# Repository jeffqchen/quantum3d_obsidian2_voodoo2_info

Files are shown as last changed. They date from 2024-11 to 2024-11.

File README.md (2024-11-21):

# Quantum3D Obsidian2 Arcade Voodoo2 Info

q3d_cover

I have luckily obtained TWO Quantum3D Obsidian2 arcade Voodoo2 cards from a kind eBay seller. They were both broken, so I spend a few weeks investigating and fixing them up, plus designing upgrades to enhance its functionalities. I hope my work will help some of you repair and make your Q3D cards work better.

## Add-on Projects

I have designed the following mods for this card.
- VGA Input Board
- U21 Xilinx CPLD Replacement
- SLI Bridge. Both rigid & ribbon type
- Protective Armor

### VGA Input Board

 

The Q3D arcade card does not come with a VGA input like a retail Voodoo 2 card. However, it has a pin header footprint on the PCB for that purpose.

I have designed a PCB to plug into the pin header, so you can add a VGA male port, plug in the VGA output of your 2D video card via that Voodoo passthrough cable.

### U21 Xilinx CPLD Replacement

 

The U21 chip, a Xilinx CPLD, controls mainly sync signals that's output to the VGA output.

There seems to be a few situations wit this chip.
- Some arcade boards come with a security setup and this chip won't function as-is.
- Sometimes this Xilinx chip dies, and you won't have any video output on the screen.

Both situations will render the card useless. I designed a simple logic circuit to function similarly to the unlocked Xilinx CPLD.

### SLI Bridge

 

This card can do SLI! However you need to add in a few missing components before that. With that part taken care of, I've come up with a rigid SLI bridge board that helps you SLI two of these same cards, or with a reference card. The info on how to create a ribbon type cable will also be available.

### Protective Armor

This set of 3D printed armor will protect sensitive SMD components and improve handling of the card, while making the card look way more nicer. It wouldn't hurt to try!



 

## Mods

 

Solder on 2MB of EDO RAM chips to the FBI on the back of the card to make it a 12MB Voodoo 2.

 

Restore picture brightness to the full PC standard.

All information is available in the [Project Wiki](https://github.com/jeffqchen/quantum3d_obsidian2_voodoo2_info/wiki) pages.

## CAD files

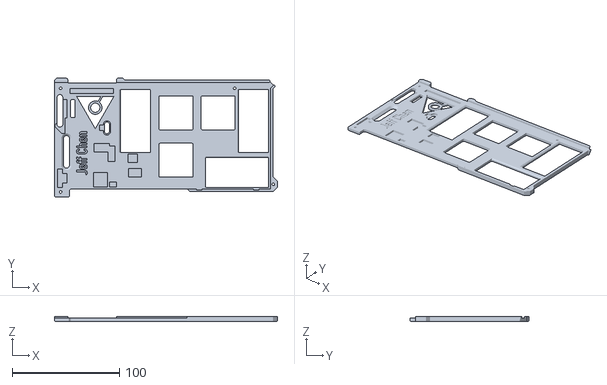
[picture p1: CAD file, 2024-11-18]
3D Print/Armor/Back.stl
208.2 x 111.2 x 5.00

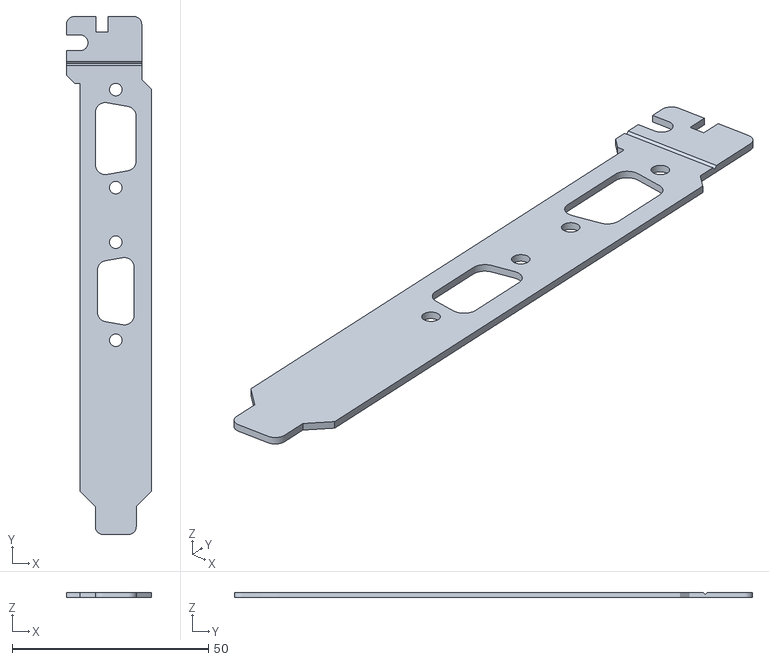
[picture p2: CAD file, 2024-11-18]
3D Print/Q3D VGA Bracket.stl
21.7 x 132.0 x 1.30

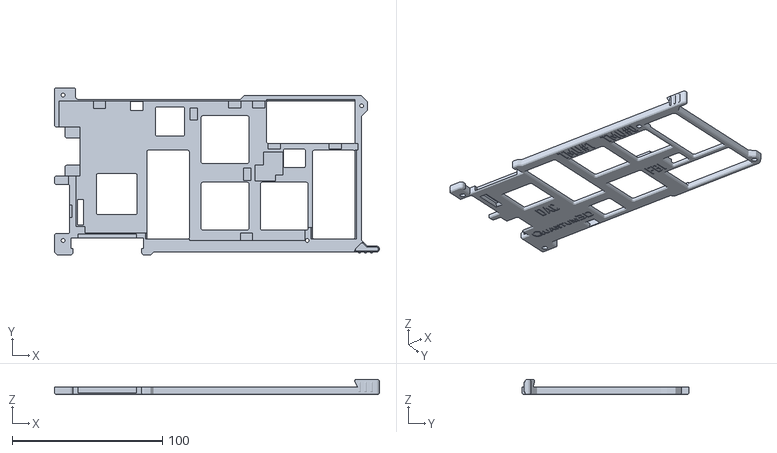
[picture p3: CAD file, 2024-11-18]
3D Print/Armor/Front.stl
216.2 x 111.2 x 10.0

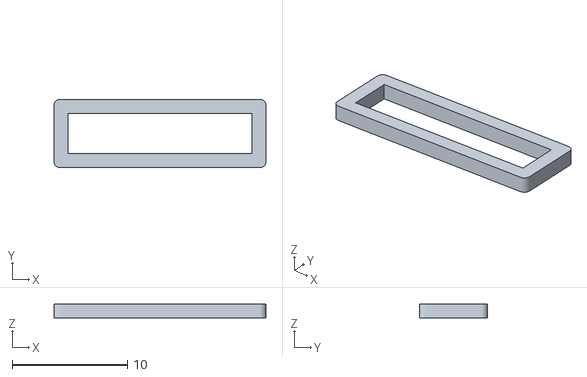
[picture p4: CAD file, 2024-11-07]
3D Print/VGA Pin Header Spacer.stl
18.4 x 5.90 x 1.25

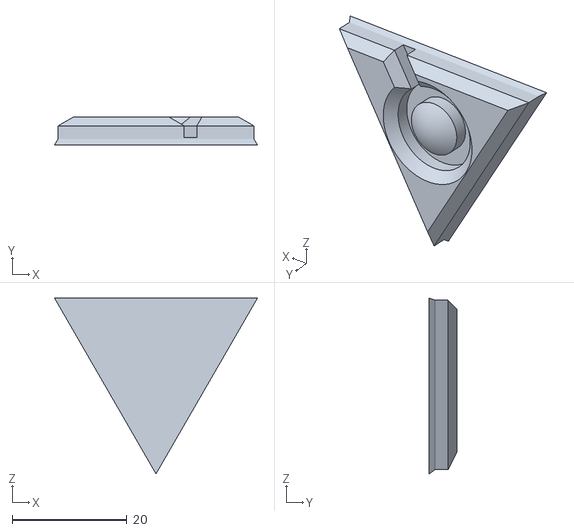
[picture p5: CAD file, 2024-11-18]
3D Print/Armor/Quantum3D Logo 3D.stl
35.4 x 4.80 x 30.6

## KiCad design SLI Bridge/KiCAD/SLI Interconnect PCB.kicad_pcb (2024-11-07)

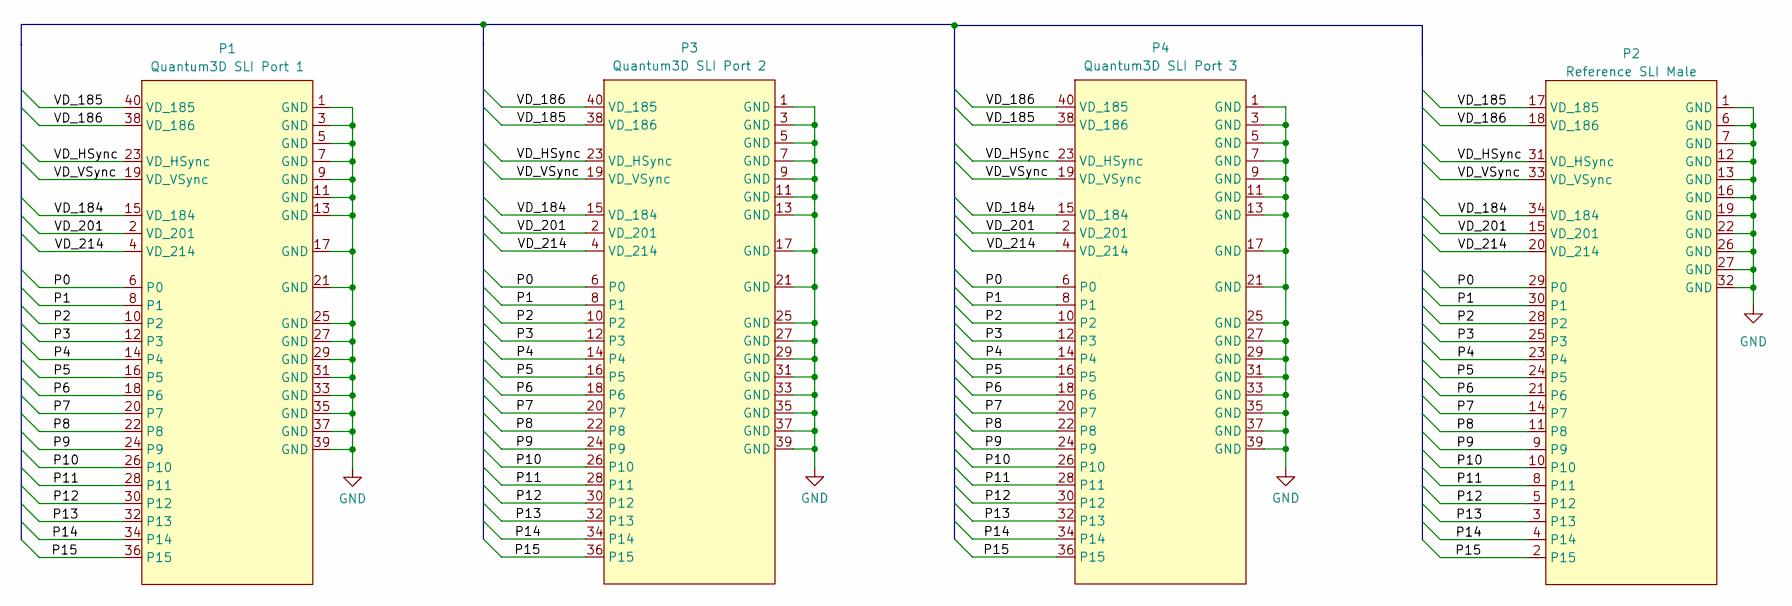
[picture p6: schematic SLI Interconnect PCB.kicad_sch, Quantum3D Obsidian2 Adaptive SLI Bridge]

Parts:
P1: Quantum3D SLI Port 1; Quantum3D_SLI_JP2_Female
P2: Reference SLI Male; Reference_SLI_Male
P3: Quantum3D SLI Port 2; Quantum3D_SLI_JP2_Female
P4: Quantum3D SLI Port 3; Quantum3D_SLI_JP2_Female

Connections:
/P0: P1.6 (P0), P2.29 (P0), P3.6 (P0), P4.6 (P0)
/P1: P1.8 (P1), P2.30 (P1), P3.8 (P1), P4.8 (P1)
/P2: P1.10 (P2), P2.28 (P2), P3.10 (P2), P4.10 (P2)
/P3: P1.12 (P3), P2.25 (P3), P3.12 (P3), P4.12 (P3)
/P4: P1.14 (P4), P2.23 (P4), P3.14 (P4), P4.14 (P4)
/P5: P1.16 (P5), P2.24 (P5), P3.16 (P5), P4.16 (P5)
/P6: P1.18 (P6), P2.21 (P6), P3.18 (P6), P4.18 (P6)
/P7: P1.20 (P7), P2.14 (P7), P3.20 (P7), P4.20 (P7)
/P8: P1.22 (P8), P2.11 (P8), P3.22 (P8), P4.22 (P8)
/P9: P1.24 (P9), P2.9, P3.24 (P9), P4.24 (P9)
/P10: P1.26 (P10), P2.10, P3.26 (P10), P4.26 (P10)
/P11: P1.28 (P11), P2.8 (P11), P3.28 (P11), P4.28 (P11)
/P12: P1.30 (P12), P2.5 (P12), P3.30 (P12), P4.30 (P12)
/P13: P1.32 (P13), P2.3 (P13), P3.32 (P13), P4.32 (P13)
/P14: P1.34 (P14), P2.4 (P14), P3.34 (P14), P4.34 (P14)
/P15: P1.36 (P15), P2.2 (P15), P3.36 (P15), P4.36 (P15)
/VD_184: P1.15 (VD_184), P2.34 (VD_184), P3.15 (VD_184), P4.15 (VD_184)
/VD_185: P1.40 (VD_185), P2.17 (VD_185), P3.38 (VD_186), P4.38 (VD_186)
/VD_186: P1.38 (VD_186), P2.18 (VD_186), P3.40 (VD_185), P4.40 (VD_185)
/VD_201: P1.2 (VD_201), P2.15 (VD_201), P3.2 (VD_201), P4.2 (VD_201)
/VD_214: P1.4 (VD_214), P2.20 (VD_214), P3.4 (VD_214), P4.4 (VD_214)
/VD_HSync: P1.23 (VD_HSync), P2.31 (VD_HSync), P3.23 (VD_HSync), P4.23 (VD_HSync)
/VD_VSync: P1.19 (VD_VSync), P2.33 (VD_VSync), P3.19 (VD_VSync), P4.19 (VD_VSync)
GND: P1.1 (GND), P1.3 (GND), P1.5 (GND), P1.7 (GND), P1.9 (GND), P1.11 (GND), P1.13 (GND), P1.17 (GND), P1.21 (GND), P1.25 (GND), P1.27 (GND), P1.29 (GND), P1.31 (GND), P1.33 (GND), P1.35 (GND), P1.37 (GND), P1.39 (GND), P2.1 (GND), P2.6 (GND), P2.7 (GND), P2.12 (GND), P2.13 (GND), P2.16 (GND), P2.19 (GND), P2.22 (GND), P2.26 (GND), P2.27 (GND), P2.32 (GND), P3.1 (GND), P3.3 (GND), P3.5 (GND), P3.7 (GND), P3.9 (GND), P3.11 (GND), P3.13 (GND), P3.17 (GND), P3.21 (GND), P3.25 (GND), P3.27 (GND), P3.29 (GND), P3.31 (GND), P3.33 (GND), P3.35 (GND), P3.37 (GND), P3.39 (GND), P4.1 (GND), P4.3 (GND), P4.5 (GND), P4.7 (GND), P4.9 (GND), P4.11 (GND), P4.13 (GND), P4.17 (GND), P4.21 (GND), P4.25 (GND), P4.27 (GND), P4.29 (GND), P4.31 (GND), P4.33 (GND), P4.35 (GND), P4.37 (GND), P4.39 (GND)

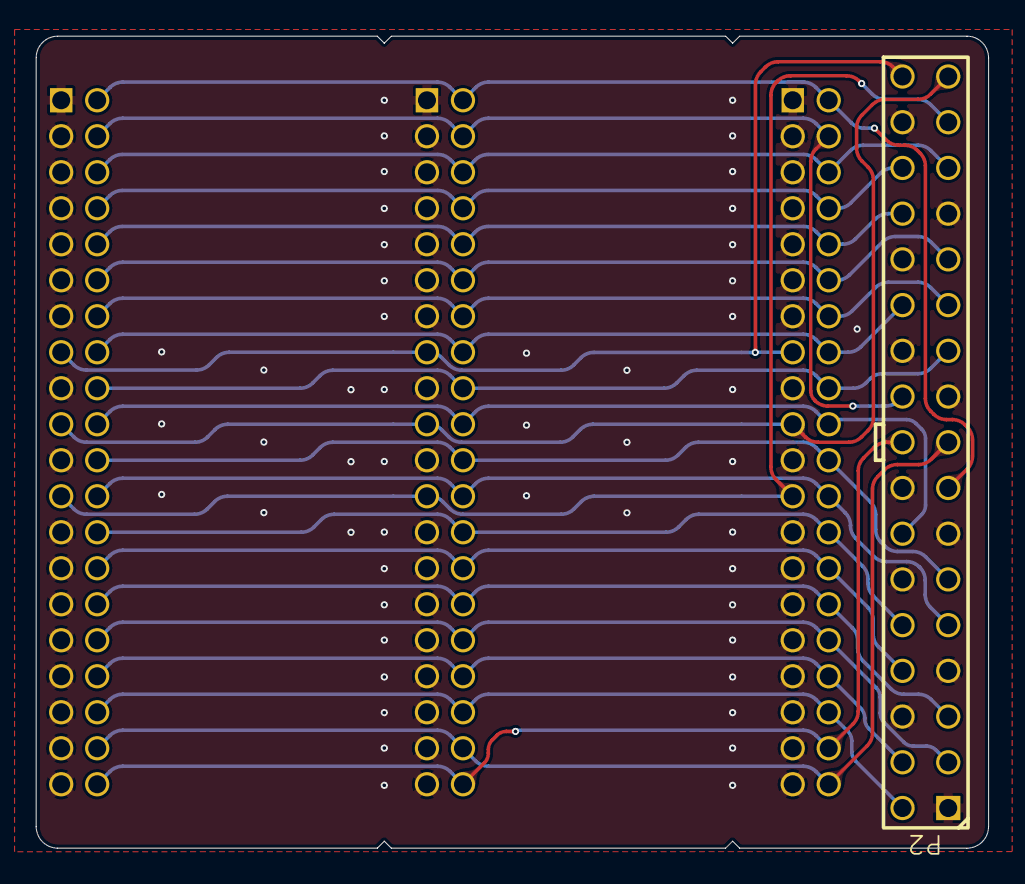
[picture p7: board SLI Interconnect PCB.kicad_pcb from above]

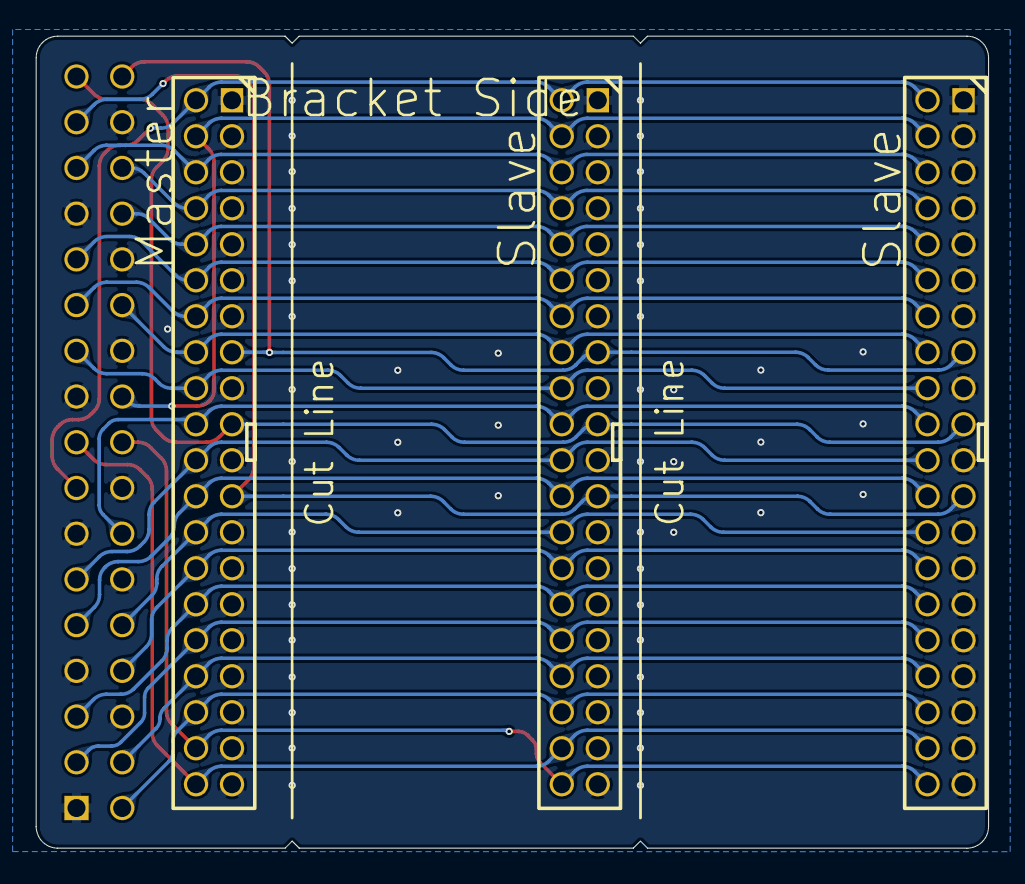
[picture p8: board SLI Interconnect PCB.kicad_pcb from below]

Board: 2 copper layers, 52.9 x 45.1 mm, 4 parts (3 on the bottom side), 24 nets.

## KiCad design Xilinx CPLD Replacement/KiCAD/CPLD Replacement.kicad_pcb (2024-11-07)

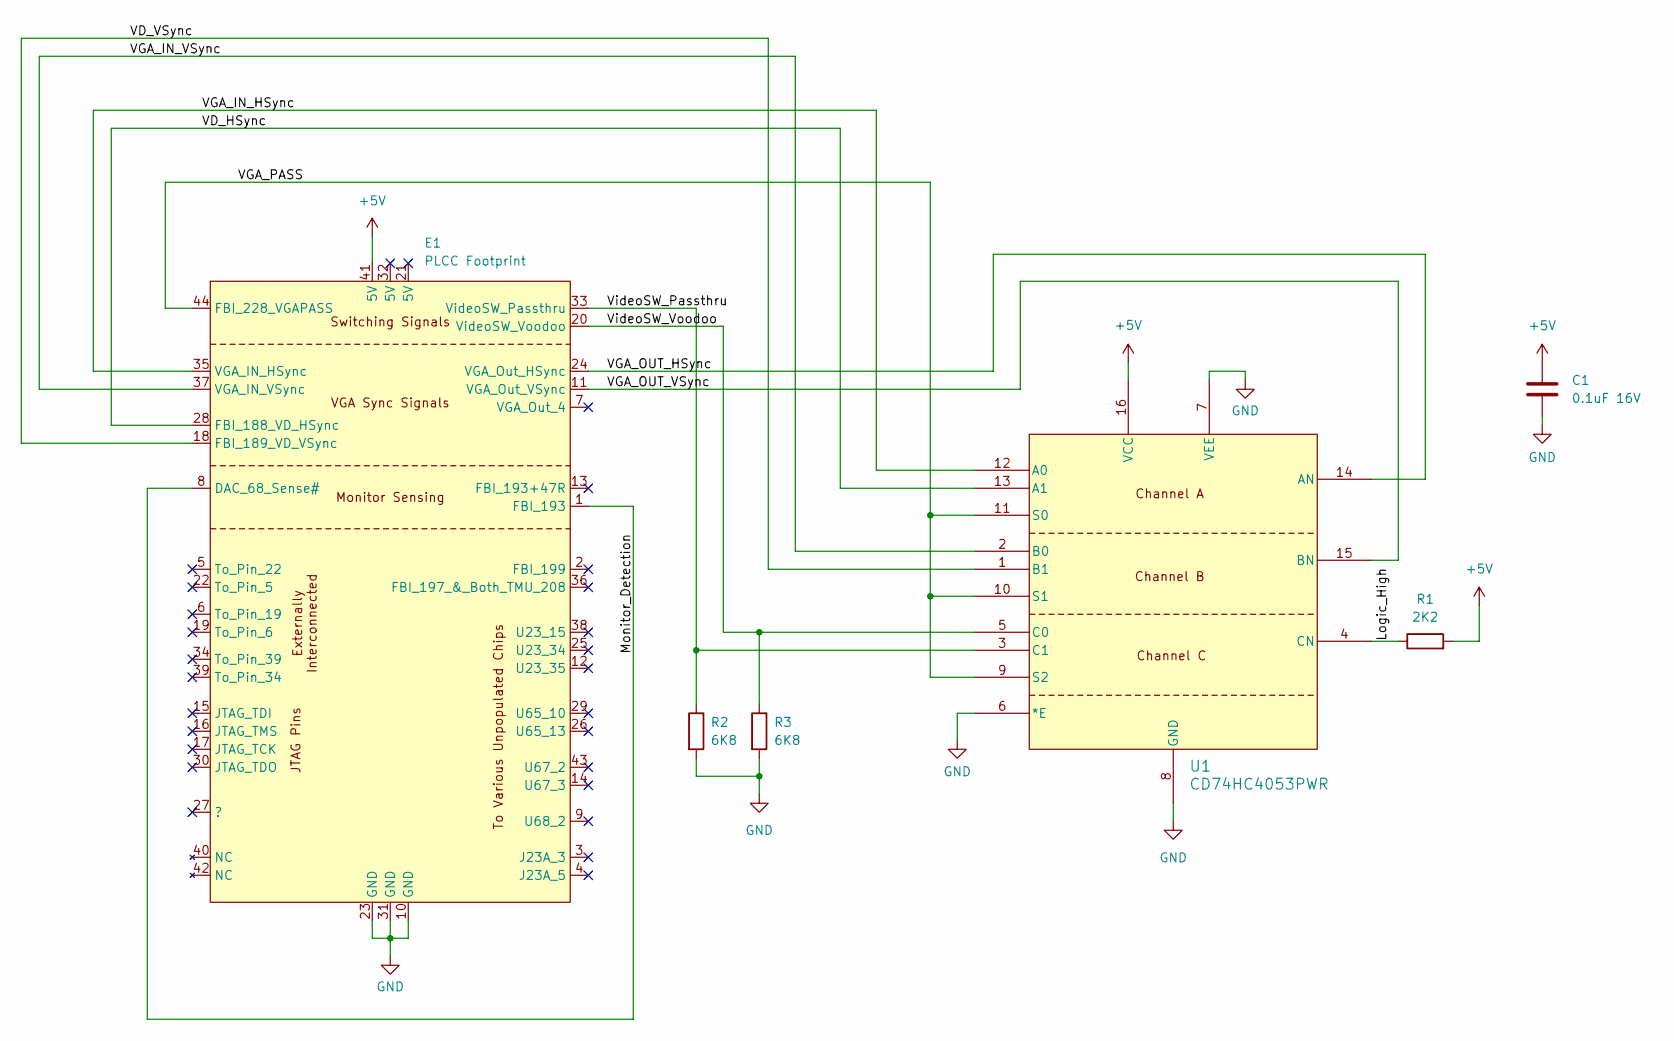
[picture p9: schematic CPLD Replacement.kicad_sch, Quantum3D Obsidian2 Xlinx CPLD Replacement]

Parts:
C1: 0.1uF 16V; R_0603_1608Metric_Pad0.98x0.95mm_HandSolder
E1: PLCC Footprint; CPLD_Replacement_44
R1: 2K2; R_0603_1608Metric_Pad0.98x0.95mm_HandSolder
R2, R3: 6K8; R_0603_1608Metric_Pad0.98x0.95mm_HandSolder
U1: CD74HC4053PWR; PW16

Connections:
+5V: C1.1, E1.41 (5V), R1.2, U1.16 (VCC)
/Logic_High: R1.1, U1.4 (CN)
/Monitor_Detection: E1.1 (FBI_193), E1.8 (DAC_68_Sense#)
/VD_HSync: E1.28 (FBI_188_VD_HSync), U1.13 (A1)
/VD_VSync: E1.18 (FBI_189_VD_VSync), U1.1 (B1)
/VGA_IN_HSync: E1.35 (VGA_IN_HSync), U1.12 (A0)
/VGA_IN_VSync: E1.37 (VGA_IN_VSync), U1.2 (B0)
/VGA_OUT_HSync: E1.24 (VGA_Out_HSync), U1.14 (AN)
/VGA_OUT_VSync: E1.11 (VGA_Out_VSync), U1.15 (BN)
/VGA_PASS: E1.44 (FBI_228_VGAPASS), U1.9 (S2), U1.10 (S1), U1.11 (S0)
/VideoSW_Passthru: E1.33 (VideoSW_Passthru), R2.1, U1.3 (C1)
/VideoSW_Voodoo: E1.20 (VideoSW_Voodoo), R3.1, U1.5 (C0)
GND: C1.2, E1.10 (GND), E1.23 (GND), E1.31 (GND), R2.2, R3.2, U1.6 (*E), U1.7 (VEE), U1.8 (GND)

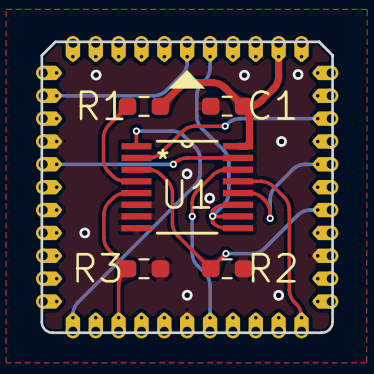
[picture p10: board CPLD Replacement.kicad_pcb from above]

Board: 2 copper layers, 16.2 x 16.2 mm, 6 parts (0 on the bottom side), 13 nets.

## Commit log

2024-11-07 KiCAD Projects & 3D Print Files
    [CPLD Replacement-B_Cu.gbr, CPLD Replacement-B_Mask.gbr, CPLD Replacement-B_Paste.gbr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]
2024-11-07 Update KiCAD Files
    [CPLD Replacement.kicad_pcb, CPLD Replacement.kicad_sch, SLI Interconnect PCB-B_Cu.gbr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]
2024-11-07 Update Q3D VGA Bracket.stl
    [Q3D VGA Bracket.stl]
2024-11-18 Upload armor
    [Back.stl, Front.stl, Q3D VGA Bracket.stl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]
